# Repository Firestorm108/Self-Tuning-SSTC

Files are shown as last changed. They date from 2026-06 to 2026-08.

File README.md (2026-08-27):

# Self-Tuning-SSTC

A solid state Tesla coil that utilizes a half-bridge configuration, automatic tuning through an antenna so that the coil is always in perfect resonance, and a 555-based interrupter. It runs straight off 120VAC with FGA60N65 IGBTs, allowing it to push many many watts. This should make for a good display at Open Sauce 2026.

# Warning

Please do NOT make this under any circumstances unless you are experienced in the field. While this is a solid state coil, it runs off 340VDC from mains and is lethal to anyone who doesn't know what they are doing. I recommened starting with a simple slayer exciter circuit or low voltage primary SSTC circuits. I do not hold any responsibility for what you choose to do with this information.

Demo: https://www.instagram.com/p/DbAHNh3O-ZV/

## Main Features:

 - Integrated 340VDC and 12VDC power supplies
 - 555 Timer Interrupter
 - Antenna feedback
 - Gate drive transformer
 - Half-bridge
 - FGA60N65 based

## Pictures:
Screenshot 2026-08-27 at 1 44 55 PM

Screenshot 2026-06-21 at 9 43 33 AM
Screenshot 2026-06-21 at 9 43 23 AM

# SSTC BOM
*You can find the spreadsheet version here: https://docs.google.com/spreadsheets/d/1Wt0Rxcv9VSmFwRn_iBSPhIluuYkqVSy19_F0Ip-qjvU/edit?usp=sharing

# Bill of Materials (BOM)

## Components

| Item | Price | Source  |
| --- | ----: | --- |
| PCB | $5 | JLCPCB  |
| 1N4007 | $0.76 | DigiKey |
| 10K Potentiometer | $3.56 | DigiKey |
| Resistor Kit | $5 | Amazon  |
| 470µF 18V Capacitors (×3) | $1 | DigiKey |
| 1N4148 | $0.40 | DigiKey |
| Ceramic Capacitor Kit | $7 | Amazon  |
| Ferrite 77 | $2 | DigiKey |
| 1N5818 | $1.50 | DigiKey |
| FGA60N65 | $15 | DigiKey |
| Thermistor (30A / 1Ω) | $10 | Amazon  |
| L7805 | $6 | Amazon  |
| KBPF307G | $1 | DigiKey |
| 0.82µF / 600V Film Capacitor | $10 | DigiKey |
| KBPC5010W | $4 | DigiKey |
| 1000µF 250V Capacitors (×2)  | $15 | DigiKey |
| LM555xN | $1.50 | DigiKey |
| LM7812 (TO-220) | $1.80 | DigiKey |
| Screw Terminals | $6 | Amazon  |
| 30AWG Magnet Wire | $22 | Amazon  |
| 4.5" × 12" PVC Tube | $21 | Amazon  |
| Topload | $20 | eBay |
| Mains Cord | $6 | Amazon  |
| 15mm M3 Standoffs | $8 | Amazon  |
| IEC Power Inlet | $9 | Amazon  |
| 12VAC Transformer | $14 | Amazon  |
| Antenna | Owned | |
| EMI Shielding Tape | $7 | Amazon  |
| Rubber Feet | Owned | |
| TO-220 Heatsinks | $8 | Amazon  |
| 12AWG Wire | $12 | Amazon  |
| IRFP460 | $10 | Amazon  |

---

## Cost Summary

| Vendor  | Total |
| --- | ---: |
| DigiKey |  **$80** |
| Amazon  | **$170** |
| eBay |  **$22** |

### Total Project Cost: **$272**

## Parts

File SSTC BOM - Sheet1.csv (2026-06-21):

Item | Price
PCB | $5 | JLCPCB
1N4007 | $0.76 | https://www.digikey.com/en/products/detail/diotec-semiconductor/1N4007/18833652
10K Pot | $3.56 | https://www.digikey.com/en/products/detail/tt-electronics-bi/P120PK-Y25BR10K/5957454
Resistor Kit | $5 | https://www.amazon.com/VIBICCK-600Pcs-Assortment-Electronic-30Values/dp/B0FRY2V145/
470uF 18V Cap 3 | $1 | https://www.digikey.com/en/products/detail/rubycon/16YXJ220MT16-3X11/3134826
1N4148 | $0.40 | https://www.digikey.com/en/products/detail/onsemi/1N4148/458603
Ceramic Kit | $7 | https://www.amazon.com/Values-Ceramic-Capacitor-100nF-Multi-Layered/dp/B0DRBV31R9
Ferrite 77 | $2 | https://www.digikey.com/en/products/detail/fair-rite-products-corp/5977001401/8599655
1N5818 | $1.50 | https://www.digikey.com/en/products/detail/diotec-semiconductor/1N5818/22191341
FGA60N65 | $15 | https://www.digikey.com/en/products/detail/onsemi/FGA60N65SMD/3137189
Thermistor 30A/1ohm | $10 | https://www.amazon.com/Ametherm-Thermistor-Inrush-Current-Limiter/dp/B071D326TB/
L7805 | $6 | https://www.amazon.com/Positive-Regulator-Three-Terminal-Regulated-Limiting/dp/B0C5M51R2Z/r
KBPF307G | $1 | https://www.digikey.com/en/products/detail/taiwan-semiconductor-corporation/KBPF307G/18720489
0.82uF/600V Film Cap | $10 | https://www.digikey.com/en/products/detail/kemet/R586R382050T0K/16903529
KBPC5010W | $4 | https://www.digikey.com/en/products/detail/evvo/KBPC5010W/27691884
2 1000uF 250V | $15 | https://www.digikey.com/en/products/detail/nichicon/LGW2E102MELB40/1966878
LM555xN | $1.50 | https://www.digikey.com/en/products/detail/texas-instruments/SE555P/380221
LM7812_TO220 | $1.80 | https://www.digikey.com/en/products/detail/texas-instruments/LM7812CT-NOPB/3901975
Screw Terminals | $6 | https://www.amazon.com/Screw-Terminal-Block-Circuit-Connectors/dp/B0FNQX9MMT/
30AWG | $22 | https://www.amazon.com/Emtel-AWG-Electrical-Transformer-Insulated/dp/B0DFHC9MDD/
4.5"x12" PVC | $21 | https://www.amazon.com/Inch-Schedule-40-PVC-Pipe/dp/B0GHPSJMCC
Topload | $20 | https://www.ebay.com/itm/358309760608
Mains Cord | $6 | https://www.amazon.com/Standard-Electronics-Computer-Printer-Monitor/dp/B09VRLJD7J
15mm M3 Standoffs | $8 | https://www.amazon.com/Black-Nylon-Standoff-Spacers-Screws/dp/B0F297R23T/
Inlet | $9 | https://www.amazon.com/FILSHU-Rocker-Switch-Socket-Module/dp/B09LGX9MQX/r
12VAC Transformer | $14 | https://www.amazon.com/Transformer-Single-Phase-Applicable-Instrument-Lndustrial/dp/B0BPM4SD2P
Antenna | Owned
EM Shielding Tape | $7 | https://www.amazon.com/Aluminum-Ductwork-Temperature-Insulation-Adhesive/dp/B0B6NDFXPN/
Rubber Feet | Owned
TO220 Heatsinks | $8 | https://www.amazon.com/Easycargo-Aluminium-25x34x12mm-Regulator-25mmx34mmx12mm/dp/B07B62V4FP/
12AWG | $12 | https://www.amazon.com/Voltage-Automotive-Primary-Security-Electrical/dp/B0D97CJYY7
IRFP460 | $10 | https://www.amazon.com/ALLECIN-IRFP460-Transistors-IRFP460NPBF-Transistor/dp/B0CBKHGVZX
Digikey Total: | $80
Amazon Total | $170
Ebay Total: | $22
Total | $272

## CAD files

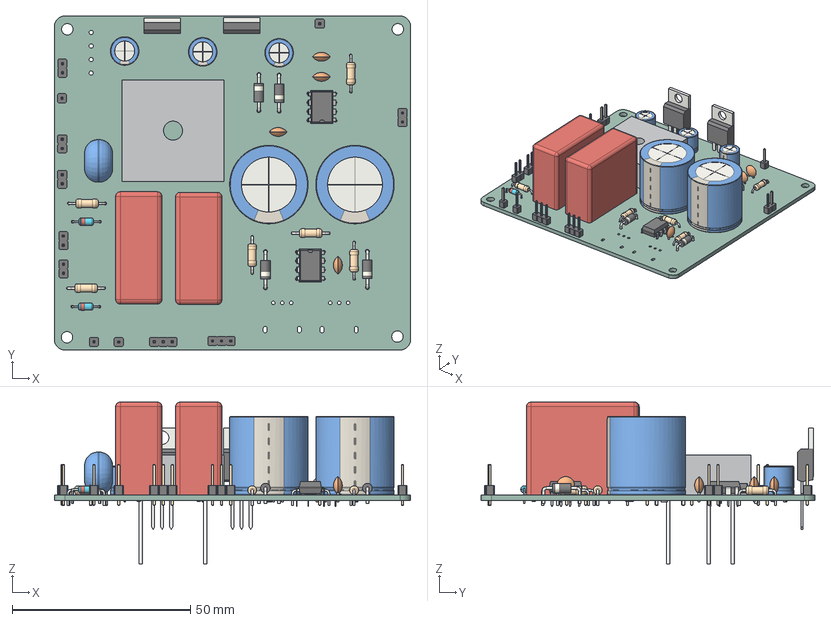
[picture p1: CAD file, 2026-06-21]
PCB Files/SelfTuningSSTC.step
100.0 x 93.7 x 45.4 mm
D_DO-41_SOD81_P10.16mm_Horizontal x 4
R_Axial_DIN0207_L63mm_D25mm_P1016mm_Horizontal x 6
CP_Radial_D80mm_P350mm x 3
D_DO-35_SOD27_P7.62mm_Horizontal x 2
C_Disc_D50mm_W25mm_P250mm x 4
PinHeader_1x02_P254mm_Vertical x 6
PinHeader_1x03_P254mm_Vertical x 2
RV_Disc_D12mm_W79mm_P75mm
TO-220-3_Vertical x 2
DIP-8_W7.62mm x 2
PinHeader_1x01_P254mm_Vertical x 4
C_Rect_L315mm_W130mm_P2750mm_MKS4 x 2
Diode_Bridge_GeneSiC_KBPC_W
CP_Radial_D220mm_P1000mm_SnapIn x 2
SelfTuningSSTC_PCB

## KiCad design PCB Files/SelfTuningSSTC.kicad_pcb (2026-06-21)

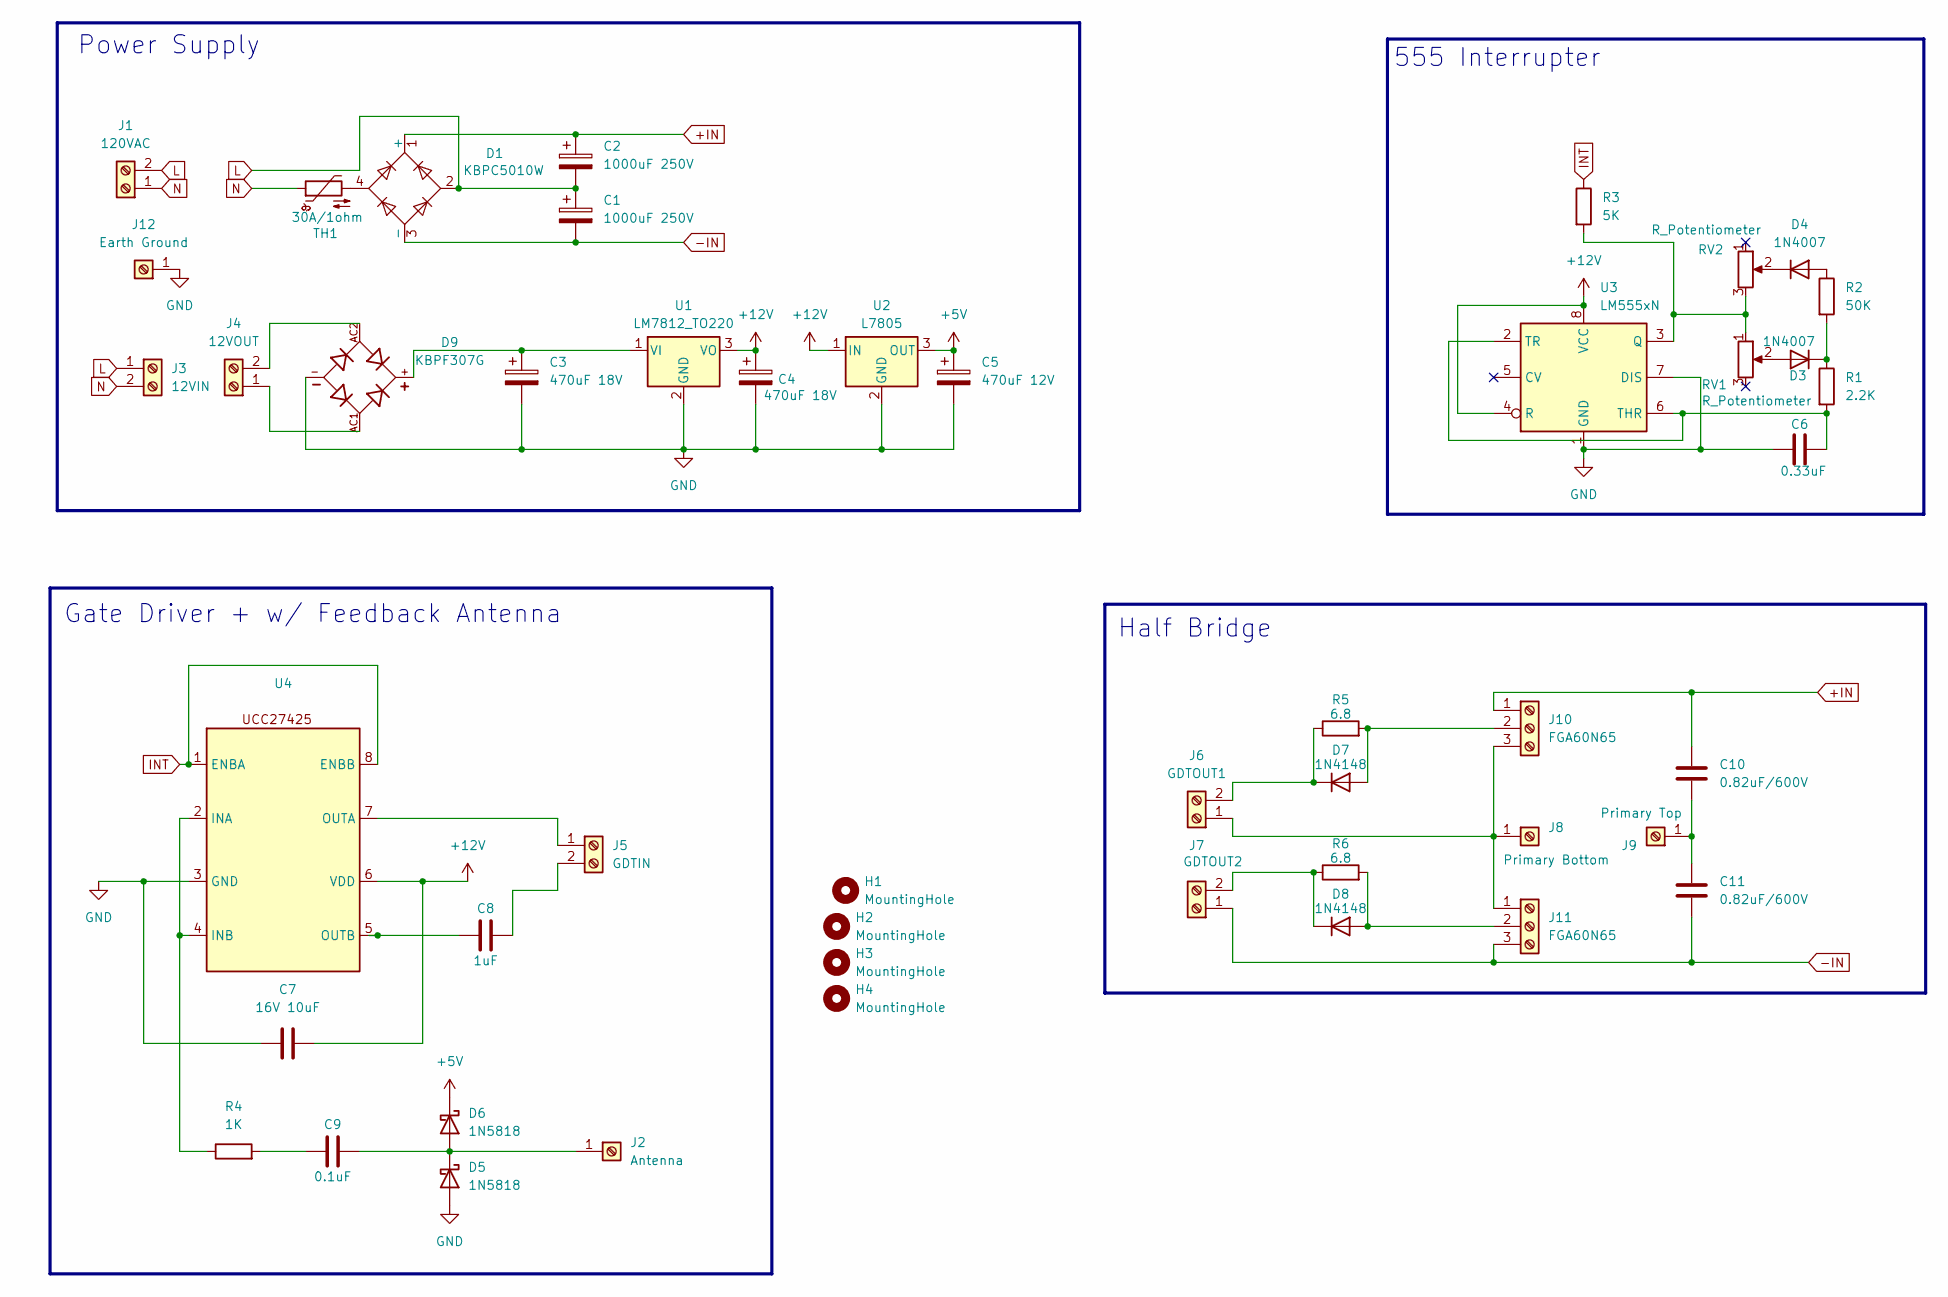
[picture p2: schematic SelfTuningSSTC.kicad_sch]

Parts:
C1, C2: 1000uF 250V; CP_Radial_D22.0mm_P10.00mm_SnapIn
C3, C4: 470uF 18V; CP_Radial_D8.0mm_P3.50mm
C5: 470uF 12V; CP_Radial_D8.0mm_P3.50mm
C6: 0.33uF; C_Disc_D5.0mm_W2.5mm_P2.50mm
C7: 16V 10uF; C_Disc_D5.0mm_W2.5mm_P2.50mm
C8: 1uF; C_Disc_D5.0mm_W2.5mm_P2.50mm
C9: 0.1uF; C_Disc_D5.0mm_W2.5mm_P2.50mm
C10, C11: 0.82uF/600V; C_Rect_L31.5mm_W13.0mm_P27.50mm_MKS4
D1: KBPC5010W; Diode_Bridge_GeneSiC_KBPC_W
D3, D4: 1N4007; D_DO-41_SOD81_P10.16mm_Horizontal
D5, D6: 1N5818; D_DO-41_SOD81_P10.16mm_Horizontal
D7, D8: 1N4148; D_DO-35_SOD27_P7.62mm_Horizontal
D9: KBPF307G; SIP350W81P380L1450H1280Q4; PARTREV B2103
H1, H2, H3, H4: MountingHole; MountingHole_3.2mm_M3
J1: 120VAC; PinHeader_1x02_P2.54mm_Vertical
J2: Antenna; PinHeader_1x01_P2.54mm_Vertical
J3: 12VIN; PinHeader_1x02_P2.54mm_Vertical
J4: 12VOUT; PinHeader_1x02_P2.54mm_Vertical
J5: GDTIN; PinHeader_1x02_P2.54mm_Vertical
J6: GDTOUT1; PinHeader_1x02_P2.54mm_Vertical
J7: GDTOUT2; PinHeader_1x02_P2.54mm_Vertical
J8: Primary Bottom; PinHeader_1x01_P2.54mm_Vertical
J9: Primary Top; PinHeader_1x01_P2.54mm_Vertical
J10, J11: FGA60N65; PinHeader_1x03_P2.54mm_Vertical
J12: Earth Ground; PinHeader_1x01_P2.54mm_Vertical
R1: 2.2K; R_Axial_DIN0207_L6.3mm_D2.5mm_P10.16mm_Horizontal
R2: 50K; R_Axial_DIN0207_L6.3mm_D2.5mm_P10.16mm_Horizontal
R3: 5K; R_Axial_DIN0207_L6.3mm_D2.5mm_P10.16mm_Horizontal
R4: 1K; R_Axial_DIN0207_L6.3mm_D2.5mm_P10.16mm_Horizontal
R5, R6: 6.8; R_Axial_DIN0207_L6.3mm_D2.5mm_P10.16mm_Horizontal
RV1, RV2: R_Potentiometer; Potentiometer_Alpha_RD901F-40-00D_Single_Vertical
TH1: 30A/1ohm; RV_Disc_D12mm_W7.9mm_P7.5mm
U1: LM7812_TO220; TO-220-3_Vertical
U2: L7805; TO-220-3_Vertical
U3: LM555xN; DIP-8_W7.62mm
U4: DIP-8_W7.62mm

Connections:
+5V: C5.1, D6.1 (K), U2.3 (OUT)
+12V: C4.1, C7.2, U1.3 (VO), U2.1 (IN), U3.4 (R), U3.8 (VCC), U4.6 (VDD)
+IN: C2.1, C10.1, D1.1 (+), J10.1
-IN: C1.2, C11.2, D1.3 (-), J7.1, J11.3
GND: C3.2, C4.2, C5.2, C6.1, C7.1, D5.2 (A), D9.-, J12.1, U1.2 (GND), U2.2 (GND), U3.1 (GND), U3.7 (DIS), U4.3 (GND)
INT: R3.1, U4.1 (ENBA), U4.8 (ENBB)
L: C1.1, C2.2, D1.2, J1.2, J3.1
N: J1.1, J3.2, TH1.1
unnamed: C9.1, R4.2
unnamed: D1.4, TH1.2
unnamed: D3.2 (A), RV1.2
unnamed: D3.1 (K), R1.1, R2.2
unnamed: D4.2 (A), R2.1
unnamed: D4.1 (K), RV2.2
unnamed: C9.2, D5.1 (K), D6.2 (A), J2.1
unnamed: D7.2 (A), J10.2, R5.2
unnamed: D7.1 (K), J6.2, R5.1
unnamed: D8.2 (A), J11.2, R6.2
unnamed: D8.1 (K), J7.2, R6.1
unnamed: D9.AC1, J4.1
unnamed: D9.AC2, J4.2
unnamed: J5.1, U4.7 (OUTA)
unnamed: C8.2, J5.2
unnamed: C10.2, C11.1, J9.1
unnamed: J6.1, J8.1, J10.3, J11.1
unnamed: C3.1, D9.+, U1.1 (VI)
unnamed: R3.2, RV1.1, RV2.3, U3.3 (Q)
unnamed: C6.2, R1.2, U3.2 (TR), U3.6 (THR)
unnamed: R4.1, U4.2 (INA), U4.4 (INB)
unnamed: C8.1, U4.5 (OUTB)

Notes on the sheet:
Half Bridge
555 Interrupter
Power Supply
Gate Driver + w/ Feedback Antenna

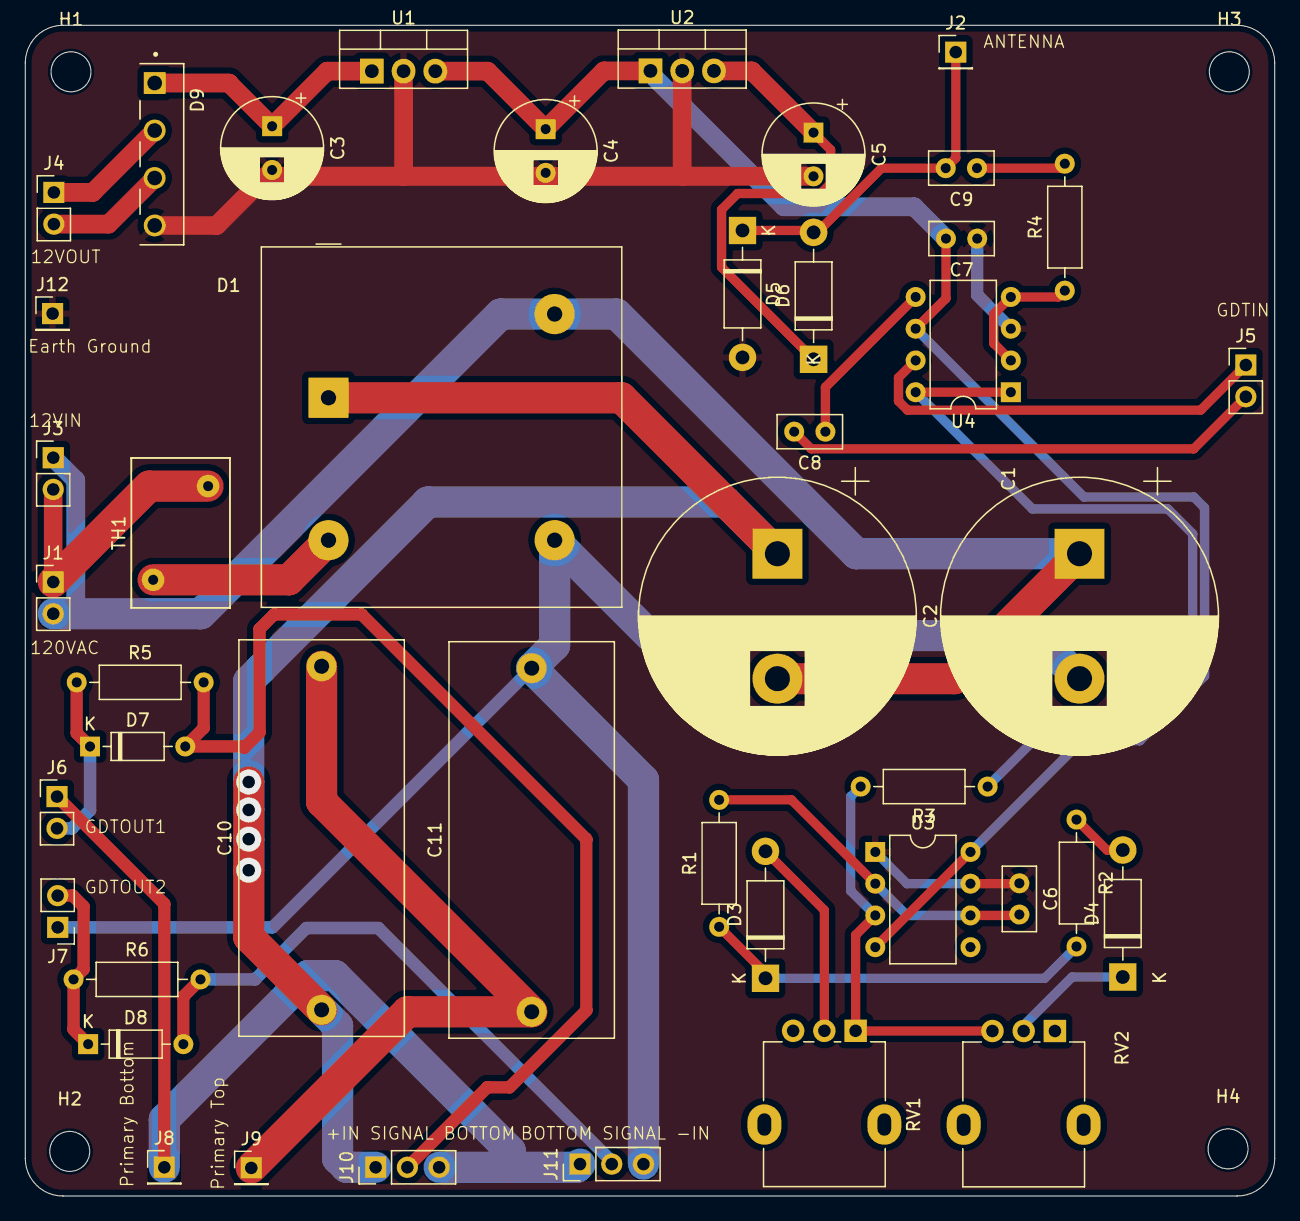
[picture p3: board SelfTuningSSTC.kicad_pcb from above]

Board: 2 copper layers, 100.0 x 93.7 mm, 48 parts (0 on the bottom side), 30 nets.

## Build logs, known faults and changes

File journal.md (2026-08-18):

---
title: "Helix"
author: "Sidd"
description: "Solid State Tesla Coil"
created_at: "2026-06-21"
total_time: "36 Hours"
---

# June 11 2026

I made the schematic today. It's inspired by LoneOceans, Steve Ward, and some other circuits. Making circuits like these and not just spamming chips like on a devboard is much much harder because you have to use actual logic.
Instead of just having function blocks and adding some decoupling caps to them, each component has a very specific purpose. Like the two clamping diodes on the antenna so that it doesn't go further than 5V.
I started with the main power supply that provides 340VDC, 12VDC, and 5VDC. Which is the logic components and the main power.

Screenshot 2026-06-11 at 6 47 15 PM

After that, I did the common useful 555 interrupter. The original design used an ATMEGA, but using a microcontroller in Tesla coils doesn't really seem like it provides much of an advantage. It's sensitive, requires programming, and has no real advantage over a 555 other than music I guess>

Screenshot 2026-06-11 at 6 47 47 PM

Finally, I did the main driving circuit. It uses the interrupter to turn it on and off, feedback from the antenna, to drive the half bridge primary,

Screenshot 2026-06-11 at 6 48 57 PM

Screenshot 2026-06-11 at 6 49 46 PM
I then swapped out some stuff for terminals so that it's all easily replaceable and the heavy components aren't on the board itself.
Screenshot 2026-06-11 at 6 53 06 PM

Here's what it looks like (now finished)

Screenshot 2026-06-11 at 7 00 14 PM

Time Spent: 4 Hours

# June 20 2026

I did footprints and layout and a bit of routing.

Screenshot 2026-06-20 at 1 08 05 PM

So I wasn't happy with my layout, mostly because I organized by components and not by circuits. So I grouped each circuit up first, and placed them together like blocks. And it came out way better and I think the routing will be nicer too.
Screenshot 2026-06-20 at 1 41 12 PM

I then did the routing and it turned out looking really good! I'm happy with this, so I'm now going to move on to the coil itself. Which hopefully won't be too much of a pain but it is going to be a pain but it's okay because it's for Open Sauce.

Screenshot 2026-06-20 at 3 18 24 PM
Screenshot 2026-06-20 at 3 18 38 PM

I calculated the coil values with JavaTC. Which is a hard AF tool to learn considering there are zero resources on this on the internet. I figured it out though and came up with a decent coil.

Screenshot 2026-06-20 at 3 53 32 PM

Time Spent: 7 Hours

# June 21

I started out designing the topload, secondary, and primary in Fusion. 

Screenshot 2026-06-21 at 7 51 07 AM

I then made the enclosure and mounted electronics, etc. Did some polished and the CAD is finished!

Screenshot 2026-06-21 at 8 23 06 AM

Yes, I am advertising my engineering account on a tesla coil :)

Screenshot 2026-06-21 at 8 23 47 AM

Then I made the BOM which sucked. Since I can't use aliexpress, I had to use amazon, digikey, and ebay which are all a pain to use compared to my dear aliexpress.

Screenshot 2026-06-21 at 9 39 02 AM

I'm gonna organize the repo now then submit

Time Spent: 4 Hours

# July 7 2026

I made the 340VDC bus power supply and the 12V logic power supply.



Time Spent: 3 Hours

# July 10-11

I kinda pulled an all nighter because I needed this done for outpost, and I made the entire driver, wound the coils, and just finished lol.






Time Spent: 18 Hours
